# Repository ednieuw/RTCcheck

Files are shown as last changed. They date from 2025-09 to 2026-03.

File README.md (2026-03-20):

# RTC check
When using DS3231 time modules some are not functioning perfect.  

RTCcheckPCB

Check up to eight DS3231 RTC's using a TCA9548A I2C multiplexer and an Arduino UNO/Nano or Arduino Nano ESP32, ESP32 C3, S3 or similar.

<br>

Control the ESP32 RTC-tester with a WIFI/serial webpage, a BLESerial app or IDE serial monitor.

When a WS2812 or SK6812 LED-strip is attached colours indicate the drift of the RTC.
An optional LDR + 10kOhm resistor can be used to regulate the LED-intensity 

This ESP32-sketch is a little overkill for its use but easy for me to add it to an existing project.

Start a simple menu by sending 'i' from a (BLE) serial terminal.<br>
For functionality info see here: https://github.com/ednieuw/Arduino-ESP32-Nano-Wordclock <br>and here: https://github.com/ednieuw/ESP32Communications.<br>
The last link is this RTC-test sketch stripped from the RTC-test code.

A smaller sketch is included for the Arduino UNO, Nano or similar. 
This UNO compatible script has no NTP time but is perfect to use if three or more DS3231 are tested.<br>
The one that drifts can be identified easily.

<br>

And that some can drift after one month can be seen above.<br>
T5 was and not temperature controlled DS1307 AT24C32<br> 
T7 was a Keyestudio DS3231<br>
The others were AT24C32 DS3231 modules.<br>
T0 was drifting seriously.<br>
<br>
<br>
Breadboard design for three RTC's but can easily be expanded to eight RTC's. See pictures below.

<br>

RTCPCBv04

The PCBV04 design was made for the Adafruit TCA9548A I2C multiplexer that happens to be 2.54mm smaller than the cheap ones.<br>
In PCBV05 it is possible to use both widths.
In PCBV06 the SQW amd 32K pins of the DS3231 can be accessed on the PCB.

RTCPCBv05

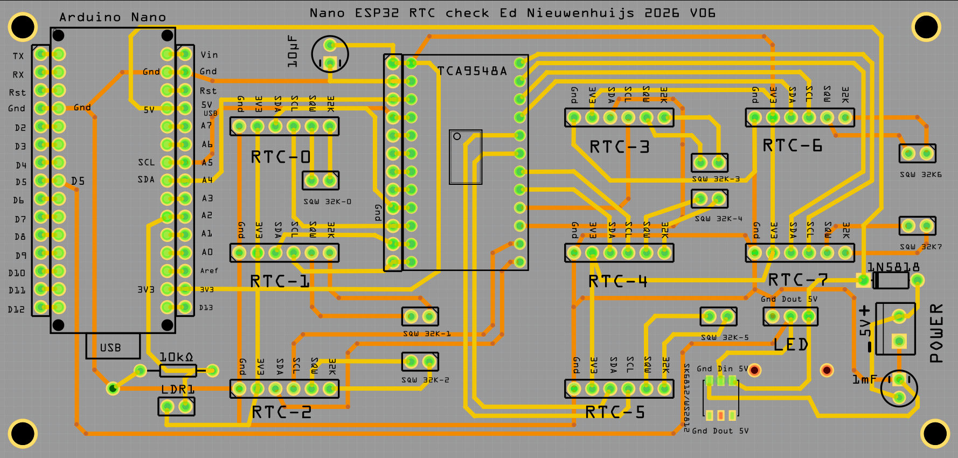
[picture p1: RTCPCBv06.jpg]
RTCPCBv06


Fritzing design with Gerber files can be found in this repository.<br>

Five PCB's [can be ordered from **PCBway**](https://www.pcbway.com) for ~25€ / $.<br> 
I am very happy with the PCB's they print for me. Just upload the Gerber-files and choose the colour of the PCB.<br> 
They are processed directly and arrive quick here in Europe. The quality is sublime and are easy to solder. 

The PCB is designed for an Arduino Nano ESP32. 

With this sketch and some wiring up to eight DS3231 modules can be tested using the NTP time server as reference.
The sketch connect with WIFI to internet and can be controlled with a BLE terminal app or the Arduino IDE serial terminal. 
```
RTC 0: 06/09/2025 17:39:30 T: 23.75 C
RTC 1: 06/09/2025 17:39:30 T: 24.25 C
RTC 2: 06/09/2025 17:39:30 T: 23.75 C
 Clock time: 06/09/2025 17:39:29 
   NTP time: 06/09/2025 17:39:30 
```

IMG_4759(1)
Running on Arduino Nano ESP32 with DS3231 connected to 3.3V pin.

IMG_4748(1)

Running on Arduino Nano Every with DS3231 connected to 5V pin. (But the DS3231's also run with the 3.3V pin)

```
___________________________________
I Menu, II long menu
F Print time differences from NTP
! See RTC times
& Update system time all RTC times
U Update system time in RTC U0-U7
R Reset settings
@ Restart
___________________________________
Slope: 1     Min: 1     Max: 255 
BLE name: RTCtest
IP-address: 192.168.178.94/update
WIFI=On NTP=On BLE=On FastBLE=Off
26/12/2025 16:03:10 
___________________________________

___________________________________
A SSID B Password C BLE beacon name
D Date (D15012021) T Time (T132145)
E Timezone  (E<-02>2 or E<+01>-1)
F Print time differences from NTP
G Scan WIFI networks
I Info menu, II long menu 
K LDR reads/sec toggle On/Off
N Display off between Nhhhh (N2208)
P Status LED toggle On/Off
R Reset settings, @ Reset MCU
U Update system time in RTC U0-U7
--Light intensity settings (1-250)--
S Slope, L Min, M Max  (S50 L5 M200)
W WIFI X NTP& Z WPS CCC BLE + Fast BLE
RTC: ! See, & Update all RTC's
Ed Nieuwenhuijs Nov 2025
___________________________________
Slope: 1     Min: 1     Max: 255 
SSID: FRITZ!BoxEd
BLE name: RTCtest
IP-address: 192.168.178.94/update
Timezone:CET-1CEST,M3.5.0,M10.5.0/3
WIFI=On NTP=On BLE=On FastBLE=Off
Rotary=Off Membrane=Off  DS3231=Off
WS2812 strip with 14 LEDs (switch %)
Software: ESP32_RTCcheckV011.ino
ESP32 Arduino core version: 3.3.5
26/12/2025 16:03:14 
___________________________________
```

<br>
Eight RTC's, a WS2812 LED-strip and LDR to control the LED intensity. 

### The Software
All the specific code for DS3231-test in this code is labelled with RTC8.

If searching for **RTC8** it is easy to find.  
```
//--------------------------------------------
// RTC8 
//-------------------------------------------- 
RTC_DS3231 rtc[MAX_RTC]; 
bool rtcActive[MAX_RTC] = {false};  
int activeRTCCount     = 0;

//--------------------------------------------
// RTC8 Initialyse all connected RTC's
//--------------------------------------------
void SetupRTCs(void) 
{
  Serial.println("DS3231 RTC Multiplexer Test");
  Serial.println("===========================");
  sprintf(sptext, "Software: %s", SoftwareName());  Tekstprintln(sptext);   
  
  Serial.print("TCA9548A search on addres 0x"); 

```

### Connect via Bluetooth
To make life easy it is preferred to use a phone or tablet and a Bluetooth communication app to enter the WIFI credentials into the clock.<br>

 	 	 
BLESerial nRF	BLE Serial Pro	Serial Bluetooth Terminal
- Download a Bluetooth UART serial terminal app on your phone, PC, or tablet.<br>

- For IOS iPhone or iPad (Buy this one to support me): [BLE Serial Pro](https://apps.apple.com/nl/app/ble-serial-pro/id1632245655?l=en).<br>
Or the free, less sophisticated app: [BLE serial nRF](https://apps.apple.com/nl/app/bleserial-nrf/id1632235163?l).<br>
Tip: Turn on Fast BLE with option + in the menu for a faster transmission.

- For Android use: [Serial Bluetooth terminal](https://play.google.com/store/apps/details?id=de.kai_morich.serial_bluetooth_terminal). <br>
Do not turn on Fast BLE in the menu. (Off = default)

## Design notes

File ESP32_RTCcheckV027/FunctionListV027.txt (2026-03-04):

void setup()                                                                                // ARDUINO Setup.
void loop()                                                                                 // ARDUINO Loop.
void loop2()                                                                                // ARDUINO Loop.
void CheckDevices(void)                                                                     // COMMON Check connected input devices.
void EverySecondCheck(void)                                                                 // COMMON Update routine.
void Every100mSecCheck(void)                                                                // COMMON Update routine.
void EveryMinuteUpdate(void)                                                                // COMMON Update routine done every minute.
void EveryHourUpdate(void)                                                                  // COMMON Update routine done every hour.
void EveryDayUpdate(void)                                                                   // COMMON Update routine done every day.
void UpdateStatusLEDs(int Toggle)                                                           // COMMON Update routine for the status LEDs.
void SetStatusLED(int Red, int Green, int Blue)                                             // COMMON Control the RGB LEDs on the Nano ESP32.
void SetNanoLED13(int intensity)                                                            // COMMON Control orange LED D13 on the Arduino.
void SetPCBLED09(int intensity)                                                             // COMMON Control the RGB LED on the PCB.
void SetPCBLED10(int intensity)                                                             // COMMON Control the RGB LED on the PCB.
void SerialCheck(void)                                                                      // COMMON check for serial input.
void Reset(void)                                                                            // COMMON Reset to default settings. BLE On, WIFI NTP Off.
void ResetCredentials(void)                                                                 // COMMON Reset to empty credential settings WIFI, NTP, BLE ON.
void Tekstprint(char const *tekst)                                                          // COMMON common print routines.
void Tekstprintln(char const *tekst)                                                        // COMMON common print routines.
void TekstSprint(char const *tekst)                                                         // COMMON common print routines.
void TekstSprintln(char const *tekst)                                                       // COMMON common print routines.
void Tekstprintf(const char* fmt, ...)                                                      // COMMON Formatted Tekst print.
void Tekstprintlnf(const char* fmt, ...)                                                    // COMMON Formatted Tekstprintln.
void WTekstappend(char const *tekst, char const *prefix, char const *suffix, bool newline)  // COMMON Print web menu page and BLE menu.
void WTekstprintln(char const *tekst)                                                       // COMMON Print web menu page and BLE menu.
void WTekstprintln(char const *tekst, char const *prefix, char const *suffix)               // COMMON Print web menu page and BLE menu.
void WTekstprint(char const *tekst)                                                         // COMMON Print web menu page and BLE menu.
void WTekstprint(char const *tekst, char const *prefix, char const *suffix)                 // COMMON Print web menu page and BLE menu.
int SConstrainInt(String s,byte first,byte last,int low,int up)                             // COMMON Constrain a string with integers.
int SConstrainInt(String s,byte first,          int low,int up)                             // COMMON Constrain a string with integers.
void InitStorage(void)                                                                      // COMMON Init and check contents of EEPROM.
void StoreStructInFlashMemory(void)                                                         // COMMON Store mem.struct in FlashStorage or SD.
void StoreIRRemoteInFlashMemory(void)                                                       // COMMON Save IR remote settings.
void GetStructFromFlashMemory(void)                                                         // COMMON Get data from FlashStorage.
void GetIRRemoteFromFlashMemory(void)                                                       // COMMON Load IR remote settings from FlashStorage.
void SWversion(void)                                                                        // COMMON Version info.
void SWversion(bool Small)                                                                  // COMMON Version info.
void PrintLine(byte Lengte)                                                                 // COMMON Print a _ line of n length.
void ReworkInputString(String InputString)                                                  // COMMON Input from Bluetooth, Serial or HTML page.
void PrintTimeInputMethod(byte Im)                                                          // COMMON Print time input method.
void PrintMem(void)                                                                         // COMMON Print permanent Mem memory.
void StoredStartHeaps()                                                                     // COMMON Print memory space.
void StoredStartHeaps(bool Store)                                                           // COMMON Print memory space.
void PrintHeaps(void)                                                                       // COMMON Print memory space.
int ReadLDR(void)                                                                           // COMMON LDR reading are between 0 and 255.
void Displaytime(void)                                                                      // CLOCK Say the time and load the LEDs.
void DimLeds(bool print)                                                                    // CLOCK Dim the leds measured by the LDR and print values.
void ColorLeds(char const *Tekst, int FirstLed, int LastLed, uint32_t RGBWColor)            // LED Set color for LEDs in strip and print tekst.
void ColorLed(int Lednr, uint32_t RGBWColor)                                                // LED Set color for LEDs in strip and print tekst.
void LedsOff(void)                                                                          // LED Clear display settings of the LEDs.
void Laatzien(int Delaymsec)                                                                // LED Turn On and the LEDs off after Delaymsec milliseconds.
void ShowLeds(void)                                                                         // LED Push data in LED strip to commit the changes.
void SetBrightnessLeds(byte Bright)                                                         // LED Set brighness of LEDs.
void Stripfill(uint32_t RGBWColor, int FirstLed, int NoofLEDs)                              // LED Set brighness of LEDs.
uint32_t StripGetPixelColor(int Lednr)                                                      // LED Set brighness of LEDs.
void LEDstartup(uint32_t LEDColour)                                                         // LED Synchronize the colour of the LEDstrip with the Status LED.
uint32_t HSVToRGB(double H, double S, double V)                                             // LED convert HSV to RGB  h is from 0-360, s,v values are 0-1.
uint32_t FuncCRGBW( uint32_t Red, uint32_t Green, uint32_t Blue, uint32_t White)            // LED function to make RGBW colour.
void ClearScreen(void)                                                                      // DISPLAY Clear the display.
void StartLeds(void)                                                                        // DISPLAY Initialyse the LEDstrip for WS2812 or SK6812 LEDs.
void WriteLightReducer(int amount)                                                          // CLOCK In- or decrease light intensity value i.e. Slope.
void InitTimeSystem(void)                                                                   // TIME Initialize time system (DS3231 + NTP + internal RTC).
void SetSystemTimeToCompileTime(void)                                                       // TIME Set system time to compile time using basic functions.
time_t GetTijd(bool printit)                                                                // TIME Get current time from best available source.
DateTime GetLocalDateTime()                                                                 // NTP Return local time as RTClib DateTime.
bool GetNTPtime(bool printit)                                                               // NTP print the NTP time for the timezone set.
bool IsDS3231I2Cconnected(void)                                                             // DS3231 check for I2C connection.
float GetDS3231Temp(void)                                                                   // DS3231 temperature.
void SetDS3231Time(void)                                                                    // DS3231 RTC ESP32 -> DS3231.
void GetDS3231Time(bool printit)                                                            // DS3231 reads time in module DS3231.
void PrintTimeHMS()                                                                         // RTC Fill sptext with time as HMS hh:mm:ss.
void PrintTimeHMS(byte format)                                                              // RTC Fill sptext with time as HMS hh:mm:ss.
void SetRTCTime(void)                                                                       // RTC Set time in ESP32 using global timeinfo struct.
void SetSystemTime(time_t t)                                                                // RTC Set RTC time using Unix timestamp.
void PrintAllClockTimes(void)                                                               // CLOCK Print all the times available.
void SendMessageBLE(std::string Message)                                                    // BLE SendMessage by BLE Slow in packets of 20 chars.
void StartBLEService(void)                                                                  // BLE Start BLE Service.
void CheckBLE(void)                                                                         // BLE Start BLE Service.
void WiFiEvent(WiFiEvent_t event)                                                           // WIFI WIFIEvents.
void ScanWIFI(void)                                                                         // WIFI Scan for WIFI stations and print a list of networks found.
void ConnectWIFI(void)                                                                      // WIFI Check for WIFI router SSID and password.
void CheckRestoreWIFIconnectivity(void)                                                     // WIFI Check if WIFI is still connected and if not restore it.
bool StartWIFI_NTP(void)                                                                    // WIFI Start WIFI connection and NTP service.
void NTPnotify(struct timeval* tv)                                                          // NTP functions.
void CheckandPrintNTPsynced(void)                                                           // NTP functions.
void setTimezone()                                                                          // NTP functions.
void initSNTP()                                                                             // NTP functions.
bool wait4SNTP()                                                                            // NTP Get a NTP time and wait max 2.5 sec.
void CheckWIFIcommand(void)                                                                 // WIFI Check for a Pending command received from the web page.
void WebPage(void)                                                                          // WIFI WEBPAGE.
void notFound(AsyncWebServerRequest *request)                                               // WIFI WEBPAGE.
void StartAPMode(void)                                                                      // WIFI WEBPAGE Login credentials Access Point page with 192.168.4.1.
void wpsInitConfig()                                                                        // WIFI WPS functions.
void wpsStart()                                                                             // WIFI WPS functions.
void wpsStop()                                                                              // WIFI WPS functions.
String wpspin2string(uint8_t a[])                                                           // WIFI WPS functions.
void OnewireKeypad3x4Check(void)                                                            // KEYPAD check for Onewire Keypad input.
void OnewireKeypad3x1Check(void)                                                            // KEYPAD check for Onewire Keypad input with 5V and 1.1, 4.7, 4.7, 4.7 kOhm resistors.
void Keypad3x1Check(void)                                                                   // KEYPAD 3x1 Init.
void RotaryEncoderCheck(void)                                                               // KY-040 ROTARY check if the rotary is moving.
void ProcessKeyPressTurn(int encoderPos)                                                    // CLOCK KY-040 Rotary or Membrane 3x1 processing input.
void Start_IRreceiver(void)                                                                 // IR-RECEIVER Start alarge or tiny IR-RECEIVER.
void Init_IRreceiver(String* ButtonTempNames, byte numButtons)                              // IR-RECEIVER Init.
uint16_t IrReceiverDecode(void)                                                             // IR-RECEIVER Decode received signal,.
void ProcessLearningMode(decode_type_t protocol, uint16_t command, uint16_t address)        // IR-RECEIVER Decode received signal,.
void ProcessRecognitionMode(decode_type_t protocol, uint16_t command, uint16_t address)     // IR-RECEIVER Decode received signal,.
void StartIRLearning(void)                                                                  // IR-RECEIVER Initializes learning mode.
void PrintAllMappings(void)                                                                 // IR-RECEIVER Shows learned buttons.
void ResetAllIRremoteSettings(void)                                                         // IR-RECEIVER Reset all settings.
int RecognizeButton(decode_type_t protocol, uint16_t command, uint16_t address)             // IR-RECEIVER Identifies button pressed.
void ReworkIRremoteValue(int ButtonNamesNr)                                                 // IR-RECEIVER ReworkRemoteValue.
void AdjustTime(int DeltaHours, int DeltaMinutes, int DeltaSeconds)                         // IR-RECEIVER Adjust current time by hours/minutes/seconds.
void ToggleIRpower(void)                                                                    // IR-RECEIVER Turn On or off Remote control.
void InitLogBuffer()                                                                        // LOGBUFFER Initialize circular logging buffer.
void AddLog(const char* msg)                                                                // LOGBUFFER Add a log line (raw C-string). Always ends with '\n'.
void HandleTekstPrint(AsyncWebServerRequest* request)                                       // LOGBUFFER Printlast 500 lines.
void HandleTekstDownload(AsyncWebServerRequest *request)                                    // LOGBUFFER Stream all the circular log buffer directly to the client.
void SetupRTCs(void)                                                                        // RTC8 Initialyse all connected RTC's.
void PrintRTCtimes(void)                                                                    // RTC8 Print RTC times.
void PrintDifRTCtimes(void)                                                                 // RTC8 Print RTC differences from NTP.
void UpdateRTCTimeLEDs(void)                                                                // RTC8 Update the time difference in the LEDs.
void CalcDifRTCtimes(void)                                                                  // RTC8 Calculate difference in sec from NTP.
void selectTCAChannel(uint8_t channel)                                                      // RTC8 Function to select TCA9548A channel.
void SetTimeForRTC(int rtcIndex, DateTime newTime)                                          // RTC8 set Time For RTC.
void SetNTPTimeForRTC(int rtcIndex)                                                         // RTC8 set current NTP Time For RTC Number X.
void PrintTimeForRTC(int rtcIndex)                                                          // RTC8 Print Time For RTC.
float GetTemperatureForRTC(int rtcIndex)                                                    // RTC8 get Temperature For RTC.
void SynchronizeAllRTCs()   // Zoek eerste actieve RTC als referentie                       // RTC8 Synchronize all RTC's with current time.
void SetCurrentTime()                                                                       // RTC8 Set time by hand in serial monitor.
void SetTempColor(int Lednr, float temp)                                                    // RTC8 Set Temperature Color.
float GetMedianRTCTemperature(void)                                                         // RTC8 Get media temperature of all active LEDs.

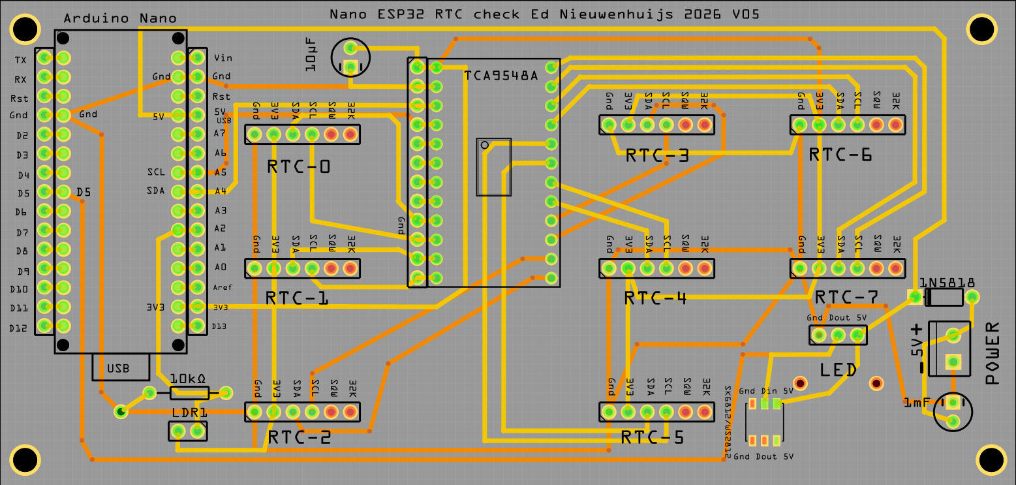
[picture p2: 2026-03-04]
PCBdesign/RTCPCBv05.jpg

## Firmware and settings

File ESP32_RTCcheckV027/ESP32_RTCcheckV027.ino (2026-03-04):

/* 
 Author      : Ed Nieuwenhuijs ednieuw.nl
 Changes V001: Derived from ESP32Arduino_WordClockV098.ino
 Changes V002:  
 Changes V003: LED crashes with some rmt error. Runs on ESP32-S3-WROOM-DevKitC-1
 Changes V004: WIFI not connecting. Added in StartAPmode()  xTaskCreatePinnedToCore(WebServerTask,"WebServerTask", 4096, NULL, 1, NULL, 1 ); 
 Changes V005: WIFI not connecting. Added WS2812 and SK6812 LED-strip functionality to GPIO-pin 8 
 Changes V006: Equal to ESP32Arduino_WordClockV105.ino
 Changes V007: crashes when using EDSoftLED
 Changes V008: Equal to ESP32Arduino_WordClockV112.ino
 Changes V009: Added Title in WebPage() 
 Changes V010: Time functions updated. You can compile now By Arduino pin (default)
 Changes V011: Equal to ESP32Arduino_WordClockV132.ino
 Changes V012: Equal to ESP32_WordClockV150. Added RTCcheck V011 
 Changes V013: NUMLED 1 -> 14 LEDS. snprintf in SWversion() Timestamp/min ||hour in menu
 Changes V014: Print time /min /ht /off K2 K1 K0
 Changes V015: Equal to ESP32Arduino_WordClockV153.ino
 Changes V016: Added DoNotLog flag. Removed action="/get" <form id="commandForm" action="/get">
               changed to char* :-> PrintRTCTime());PrintNTPtime());PrintUTCtime()); PrintDS3231Time());
 Changes V017: Double printing of menu in Logging solved. Option K2 debugged. Equal to ESP32_WordClockV159
 Changes V018: Cosmetic.
 Changes V019: Cosmetic. Equal to ESP32Arduino_WordClockV160.ino
 Changes V020: Stable 
 Changes V021: Added option U in menu 
 Changes V022: Ringbuffer as in woordclockV183
 Changes V023: Cleaning up and cosmetics.  
 Changes V024: Ringbuffer long log file as download
 Changes V025: Temp -10C _ 60C -> 15C _ 25C
 Changes V026: Added CheckWIFIcommand() to avoid WIFI crashes when a command take several seconds to end, like LEDtest()
 Changes V026: changed delimiters in time log. Temp  15C _ 25C -> 10C - 30C and color calculation  LED10.
*********************
How to compile: 
Install ESP32 boards
Board: ESP32 core version >3.2.0 
Partition Scheme: With FAT
Pin Numbering: By Arduino pin (default)     -- > with EdsoftLED both can be used
               By GPIO number (legacy).     -- > When using NEOpixel
               when using By Arduino pin Error: Adafruit_NeoPixel/esp.c:78:(.text.espShow+0x55): undefined reference to `digitalPinToGPIONumber' 
USB mode: Normal (Tiny USB)
**********************

ESP32-S3-WROOM-DevKitC-1
Option	    Value
Board:      ESP32-S3 DEV Module on ESP32 core 3.3.3 
USB         CDC on Boot	Enabled
USB Mode	  Hardware CDC and JTAG (or just Hardware CDC)
Upload Mode	UART0 / Hardware Serial
Flash Mode	QIO 80MHz (default, or leave unchanged)
Port	      Select the UART COM port (the one with a USB-to-Serial chip)

*/
// =============================================================================================================================

//------------------------------------------------------------------------------              //
// ESP32 Includes defines and initialisations
//--------------------------------------------
                      #if ESP_ARDUINO_VERSION >= ESP_ARDUINO_VERSION_VAL (5, 2, 0)            // Use EdSoftLED with ESP32 compiler.
#define USEEDSOFTLED  // Sometimes a flicker with Core 3.3.3 NEOPIXEL worka now also OK but need to set By GPIO number
                      #endif
                      #ifdef USEEDSOFTLED
#include <EdSoftLED.h>         // https://github.com/ednieuw/EdSoftLED for LED strip WS2812 or SK6812 
                      #else
#include <Adafruit_NeoPixel.h> // https://github.com/adafruit/Adafruit_NeoPixel  *** USE GPIO NUMBERING and compile By GPIO number (legacy) 
                      #endif
#include <Preferences.h>
#include <NimBLEDevice.h>      // For BLE communication. !!!Use NimBLE version 2.x.x  https://github.com/h2zero/NimBLE-Arduino
#include <WiFi.h>              // Used for web page 
#include <esp_sntp.h>          // for NTP
#include <esp_wps.h>           // For WPS
#include <ESPAsyncWebServer.h> // Used for webpage  https://github.com/ESP32Async 
#include <Update.h>            // For Over-the-Air (OTA)
#include <ESPmDNS.h>           // To show BLEname in router
#include <DNSServer.h>         // For the web page to enter SSID and password of the WIFI router 
#include <Wire.h>              // Ter zijner tijd Wire functies gaan gebruiken. Staan al klaar in de code 
#include <RTClib.h>            // Used for connected DS3231 RTC // Reference https://adafruit.github.io/RTClib/html/class_r_t_c___d_s3231.html
#include <Encoder.h>           // For rotary encoder
#include <Keypad.h>            // For 3x1 membrane keypad instead of rotary encoder by Mark Stanley & Alexander Brevig 
#include <IRremote.hpp>        // IR remote control

//------------------------------------------------------------------------------              //
// SPIFFS storage
//--------------------------------------------
Preferences FLASHSTOR;

                           #if defined(ARDUINO_NANO_ESP32)
//------------------------------------------------------------------------------              //
// PIN Assigments for Arduino Nano ESP32 (S3)
//------------------------------------------------------------------------------
 
enum DigitalPinAssignments {      // Digital hardware constants ATMEGA 328 ----
 SERRX        = D0,               // Connects to Bluetooth TX
 SERTX        = D1,               // Connects to Bluetooth RX
 encoderPinB  = D2,               //5,  // D2 left (labeled CLK on decoder)no interrupt pin (Use GPIO pin numbering for rotary encoder lib)  
 encoderPinA  = D3,               //6,  // D3 right (labeled DT on decoder)on interrupt pin
 clearButton  = D4,               //7,  // D4 switch (labeled SW on decoder)
 IRReceiverPin= D4,               // D4 Infrared receiver pin instead of rotary encoder
 LED_PIN      = D5,               //8,  // D5 / GPIO 8 Pin to control colour SK6812/WS2812 LEDs (replace D5 with 8 for NeoPixel lib)
 EmptyD6      = D6,               // D6 Empty
 EmptyD7      = D7,               // D7 Empty
 EmptyD8      = D8,               // D8 Empty 
 PCB_LED_D09  = D9,               // D9
 PCB_LED_D10  = D10,              // D10
 secondsPin   = D13               //48, // D13  GPIO48 (#ifdef LED_BUILTIN  #undef LED_BUILTIN #define LED_BUILTIN 48 #endif)
 };
 
enum AnaloguePinAssignments {     // Analogue hardware constants ----
 EmptyA0      = A0,               // Empty
 EmptyA1      = A1,               // Empty
 PhotoCellPin = A2,               // LDR pin
 OneWirePin   = A3,               // OneWirePin
 SDA_pin      = A4,               // SDA pin
 SCL_pin      = A5,               // SCL pin
 EmptyA6      = A6,               // Empty
 EmptyA7      = A7};              // Empty
 
                                  #else

//------------------------------------------------------------------------------              //
// PIN Assigments for ESP32 S3 DevKitC 1
//------------------------------------------------------------------------------  
enum DigitalPinAssignments {      // Digital hardware constants ATMEGA 328 ----
 SERRX        = 44,               // D1 Connects to Bluetooth TX
 SERTX        = 43,               // D0 Connects to Bluetooth RX
 encoderPinB  = 4,                // D2 left (labeled CLK on decoder)no interrupt pin (Use GPIO pin numbering for rotary encoder lib)  
 encoderPinA  = 5,                // D3 right (labeled DT on decoder)on interrupt pin
 clearButton  = 6,                // D4 switch (labeled SW on decoder)
 IRReceiverPin= 6,                // D4 Infrared receiver pin instead of rotary encoder
 LED_PIN      = 48,               // D5 / GPIO 8 Pin to control colour SK6812/WS2812 LEDs (replace D5 with 8 for NeoPixel lib)
 PCB_LED_D09  = 10,               // D9
 PCB_LED_D10  = 11,               // D10
 secondsPin   = 13,               // D13  GPIO48 (#ifdef LED_BUILTIN  #undef LED_BUILTIN #define LED_BUILTIN 48 #endif)
 };
 
enum AnaloguePinAssignments {     // Analogue hardware constants ----
 EmptyA0      = 10,               // Empty
 EmptyA1      = 11,               // Empty
 PhotoCellPin = 12,               // LDR pin
 OneWirePin   = 13,               // OneWirePin
 SDA_pin      = 8,                // SDA pin
 SCL_pin      = 9,                // SCL pin
 EmptyA6      = 16,               // Empty
 EmptyA7     =  17};              // Empty
                          #endif //defined(ARDUINO_NANO_ESP32)
//------------------------------------------------------------------------------              //
// LED
//------------------------------------------------------------------------------

const uint32_t  NUM_LEDS = 10;  // Used strip is 14 LEDs long. Will now clear all the LEDs at startup
#define CLEARLEDSTARTUP 9999
                     #ifdef USEEDSOFTLED
EdSoftLED LEDstrip ;//    = EdSoftLED();                                                      // Use EdSoftLED with ESP32 compiler V3.x.x. Neopixel crashes
EdSoftLED LED6812strip = EdSoftLED(NUM_LEDS, LED_PIN, SK6812WRGB);
EdSoftLED LED2812strip = EdSoftLED(NUM_LEDS, LED_PIN, WS2812RGB);
bool UsedEDSOFTLED = true;
                      #else
// LED_PIN = 8;  // bug in Neopixel library. Does not translate D5 to GPIO 8
Adafruit_NeoPixel LEDstrip;
Adafruit_NeoPixel LED6812strip = Adafruit_NeoPixel(NUM_LEDS, LED_PIN, NEO_GRBW + NEO_KHZ800); // NEO_RGBW
Adafruit_NeoPixel LED2812strip = Adafruit_NeoPixel(NUM_LEDS, LED_PIN, NEO_GRB  + NEO_KHZ800); // NEO_RGB NEO_GRB
bool UsedEDSOFTLED = false;
                      #endif
// #define MCULEDPIN 9
// Adafruit_NeoPixel MCUled = Adafruit_NeoPixel(1, MCULEDPIN, NEO_GRB + NEO_KHZ800);  //NEO_RGB NEO_GRB

//------------------------------------------------------------------------------              //
const uint32_t black    = 0x000000, darkorange    = 0xFF8C00, red        = 0xFF0000, chartreuse   = 0x7FFF00;
const uint32_t brown    = 0x503000, cyberyellow   = 0xFFD300, orange     = 0xFF8000; 
const uint32_t yellow   = 0xFFFF00, cadmiumyellow = 0xFFF600, dyellow    = 0xFFAA00, chromeyellow = 0xFFA700;
const uint32_t green    = 0x00FF00, brightgreen   = 0x66FF00, apple      = 0x80FF00, grass        = 0x00FF80;  
const uint32_t amaranth = 0xE52B50, edamaranth    = 0xFF0050, amber      = 0xFF7E00;
const uint32_t marine   = 0x0080FF, darkviolet    = 0x800080, pink       = 0xFF0080, purple       = 0xFF00FF; 
const uint32_t blue     = 0x0000FF, cerulean      = 0x007BA7, sky        = 0x00FFFF, capri        = 0x00BFFF;
const uint32_t edviolet = 0X7500BC, frenchviolet  = 0X8806CE, coquelicot = 0xFF3800;
const uint32_t greenblue= 0x00F2A0, hotmagenta    = 0xFF00BF, dodgerblue = 0x0073FF, screamingreen= 0x70FF70;
      uint32_t white    = 0xFFFFFF, lgray         = 0x666666, wgray      = 0xAAAAAA;
      uint32_t gray     = 0x333333, dgray         = 0x222222;  

//--------------------------------------------
// DS3231 CLOCK MODULE
//--------------------------------------------
#define DS3231_I2C_ADDRESS          0x68
#define DS3231_TEMPERATURE_MSB      0x11
#define DS3231_TEMPERATURE_LSB      0x12
RTC_DS3231 RTCklok; 
bool DS3231Installed = false;                                                                 // True if the DS3231 is detected

#define TCA_ADDR 0x70                 // RTC8                                                // TCA9548A I2C multiplexer adres (standaard 0x70)
#define MAX_RTC 8                     // RTC8                                                // Maximaal Noof RTC modules
uint32_t RTCdiffSec[MAX_RTC];         // RTC8                                                // Seconds deviating from NTP time

//------------------------------------------------------------------------------              //
// KY-040 ROTARY
//------------------------------------------------------------------------------                       
Encoder myEnc(encoderPinA, encoderPinB);                                                      // Use digital pin  for encoder    
long     Looptime             = 0;
byte     RotaryPress          = 0;                                                            // Keeps track display choice and how often the rotary is pressed.
bool     ChangeLightIntensity = false;                                                        // Increase or decrease slope light intensity        
uint32_t RotaryPressTimer     = 0;
byte     NoofRotaryPressed    = 0;

//--------------------------------------------                                                //
// One-wire keypad
//--------------------------------------------
bool     ChangeTime           = false;                                                        // Flag to change time within 60 seconds       
uint64_t KeyLooptime          = 0;
String   KeypadString         ="";
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
void loop() 
{
 Loopcounter++;                                                                               // a counter to check the speed of the loop
 CheckDevices();                                                                              // Check input from devices
 EverySecondCheck();                                                                          // Enter the command structure
}
void loop2()
{

}
//--------------------------------------------                                                //
// COMMON Check connected input devices
//--------------------------------------------
void CheckDevices(void)
{
 CheckBLE();                                                                                  // Something with BLE to do?
 SerialCheck();                                                                               // Check serial port every second 
 CheckWIFIcommand();                                                                          // Check if there is a command given from the web page
 if (Mem.UseRotary==1) RotaryEncoderCheck(); 
 if (Mem.UseRotary==2) Keypad3x1Check();
}
//--------------------------------------------                                                //
// COMMON Update routine 
// Performs tasks every second
//--------------------------------------------
void EverySecondCheck(void)
{
 static bool Toggle = 0;
 uint32_t msLeap = millis() - msTick;                                                         //
 if (msLeap % 100) Every100mSecCheck();
 if (msLeap > 999)                                                                             // Every second enter the loop
 {
  msTick = millis();
  GetTijd(false);                                                                             // Get the time for the seconds 
 
  Toggle = !Toggle;                                                                          // Used to turn On or Off Leds
  UpdateStatusLEDs(Toggle);
  DimLeds(TestLDR);                                                                           // Every second an intensity check and update from LDR reading 
  // SetTempColor(8, timeinfo.tm_sec/2);    
  if (shouldReboot) { delay(1000);   ESP.restart(); }                                         // After finish OTA update restart
  if (timeinfo.tm_min != lastminute) EveryMinuteUpdate();                                     // Enter the every minute routine after one minute; 
  Loopcounter=0;
 }  
}

//--------------------------------------------                                                //
// COMMON Update routine 
// Performs tasks every second
//--------------------------------------------
void Every100mSecCheck(void)
{
 if (Mem.UseRotary==3 || Mem.UseRotary==4) IrReceiverDecode();
}
//--------------------------------------------                                                //
// COMMON Update routine done every minute
//-------------------------------------------- 
void EveryMinuteUpdate(void)
{   
 lastminute = timeinfo.tm_min;  
 if (IR_PowerOnstate && ((millis() - IR_StartTime) > 290000) ) ToggleIRpower();               // Turn off Power after 300 seconds 
 GetTijd(false);
 bool ff = NoTextInLeds; 
 if (Mem.TimeMinute == 0 || Mem.TimeMinute == 2)                                              // Do not print time but do update the display                                                              // do not Print the time string every minute
    { NoTextInLeds = true; DimLeds(false); Displaytime(); }
 if (Mem.TimeMinute == 1)                                                                     // Print the time string every minute
    { NoTextInLeds = false; DimLeds(true);  Displaytime(); Tekstprintln(""); }
 NoTextInLeds = ff;   
 DimLeds(false);                                                                              // 
 if(timeinfo.tm_hour != lasthour) EveryHourUpdate();                                                                            //  if(timeinfo.tm_hour != lasthour) EveryHourUpdate(); 
}
//--------------------------------------------                                                //
// COMMON Update routine done every hour
//--------------------------------------------
void EveryHourUpdate(void)
{
 lasthour = timeinfo.tm_hour;
 if (!Mem.StatusLEDOn) SetStatusLED(0,0,0);                                                   // During startup this EveryHourUpdate is run once and will turn the status LEDs of  
 bool ff = NoTextInLeds; 
 if (Mem.TimeMinute == 2)                                                                     // Print the time string every hour
    { NoTextInLeds = false; DimLeds(true); Displaytime(); Tekstprintln(""); }
 NoTextInLeds = true; 
 Displaytime(); 
 NoTextInLeds = ff;                                                                          // Print time per hour
 if((timeinfo.tm_hour == Mem.TurnOffLEDsAtHH) && (Mem.TurnOffLEDsAtHH != Mem.TurnOnLEDsAtHH))
   { LEDsAreOff = true;  ClearScreen(); }                                                     // Is it time to turn off the LEDs?
 if(timeinfo.tm_hour == Mem.TurnOnLEDsAtHH)
   { LEDsAreOff = false;   lastminute = 99; Displaytime(); Tekstprintln(""); }                // Force a minute update to turn on LEDs
 CheckRestoreWIFIconnectivity();                                                              // Check if WIFI is still connected and if not restore it
 Mem.NVRAMmem[lasthour] =(byte)((SumLDRreadshour / NoofLDRreadshour?NoofLDRreadshour:1));     // Update the average LDR readings per hour
 SumLDRreadshour  = 0;
 NoofLDRreadshour = 0;                                                                        // and DimLEDs are used to print the time every hour 
 if (timeinfo.tm_mday != lastday) EveryDayUpdate();  
}

//--------------------------------------------                                                //
// COMMON Update routine done every day
//--------------------------------------------
void EveryDayUpdate(void)
{
 lastday           = timeinfo.tm_mday; 
 Previous_LDR_read = ReadLDR();                                                               // to have a start value and reset the Min Max measurements 
 MinPhotocell      = Previous_LDR_read;                                                       // Stores minimum reading of photocell;
 MaxPhotocell      = Previous_LDR_read;                                                       // Stores maximum reading of photocell;
// if(DS3231Installed && !Mem.UseDS3231) SetDS3231Time();                                       // If on NTP time and DS3231 installed set the correct the time in the DS3231 
 Tekstprintln(PrintRTCTime());                                                                // Print time as dd-mmm-yy hh:mm:ss
 StoreStructInFlashMemory();                                                                  // Update Mem struct once a day to store Mem.NVRAM measurementd
}

//--------------------------------------------                                                //
// COMMON Update routine for the status LEDs
//-------------------------------------------- 
void UpdateStatusLEDs(int Toggle)
{
 if(Mem.StatusLEDOn)   
   {
    SetStatusLED((Toggle && WiFi.localIP()[0]==0) * 20, 
                 (Toggle && WiFi.localIP()[0]!=0) * 20 , 
                 (Toggle &&      deviceConnected) * 20);
    SetPCBLED09( Toggle * 10);                                                                // Left LED
    SetPCBLED10((!Toggle) * 10);                                                              // Right LED
    SetNanoLED13((!Toggle) * (!Mem.UseDS3231 * 50));                                         // LED on ESP32 board. IF DS3231 in use then it is off
   }
   else
   {
    SetStatusLED(0, 0, 0); 
    SetPCBLED09(0);                                                                           //
    SetPCBLED10(0);                                                                           //
    SetNanoLED13(0);      
   }
}
//--------------------------------------------                                                //
// COMMON Control the RGB LEDs on the Nano ESP32
// Analog range 0 - 512. 0 is LED Off, 512 is max intensity
// 512 is LED off. Therefore the value is subtracted from 512
// in core 3 the value to write is 13-bit 8191 to turn off the led completely
//  rgbLedWrite(512-Red,512-Green,512-Blue);
//--------------------------------------------
void SetStatusLED(int Red, int Green, int Blue)
{
 analogWrite(LED_RED,   Red   == 0 ? 8191 : (512 - Red));
 analogWrite(LED_GREEN, Green == 0 ? 8191 : (512 - Green));
 analogWrite(LED_BLUE,  Blue  == 0 ? 8191 : (512 - Blue));
}
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

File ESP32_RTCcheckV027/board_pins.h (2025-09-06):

// board_pins.h
// Unified pin definitions for ESP32 families and Arduino Nano ESP32
// Shows used pins, safe unused pins, and unsafe pins (documented)
// Makes it easy to keep track of pin usage across boards

#pragma once

// -----------------------------------------------------------------------------
// Manual board selection (uncomment one if needed)
// #define BOARD_ESP32_S3
// #define BOARD_ESP32_C3
// #define BOARD_ESP32_H2
// #define BOARD_ARDUINO_NANO_ESP32

// -----------------------------------------------------------------------------
// Auto-detect
#if !defined(BOARD_ESP32_S3) && !defined(BOARD_ESP32_C3) && \
    !defined(BOARD_ESP32_H2) && !defined(BOARD_ARDUINO_NANO_ESP32)

  #if defined(ARDUINO_ESP32S3_DEV) || defined(CONFIG_IDF_TARGET_ESP32S3)
    #define BOARD_ESP32_S3
  #elif defined(ARDUINO_ESP32C3_DEV) || defined(CONFIG_IDF_TARGET_ESP32C3)
    #define BOARD_ESP32_C3
  #elif defined(ARDUINO_ESP32H2_DEV) || defined(CONFIG_IDF_TARGET_ESP32H2)
    #define BOARD_ESP32_H2
  #elif defined(ARDUINO_NANO_ESP32)
    #define BOARD_ARDUINO_NANO_ESP32
  #else
    #warning "Unknown board: please define BOARD_ESP32_S3 / C3 / H2 / NANO manually"
  #endif
#endif

// -----------------------------------------------------------------------------
// ESP32-S3
// Safe GPIOs: 1–14, 16–21, 33–48
#ifdef BOARD_ESP32_S3

  // ⚠️ Unsafe pins (don’t use!)
  // 0 = strapping (boot), 15 = USB D-, 16/17 = USB D+ (if native USB),
  // 19/20 = XTAL, 46 = strapping
  // Flash/PSRAM pins: 26–32 (not exposed)

  // ➖ Empty safe pins
   #define PIN_BTN       0
  #define EMPTY_01   1
  #define EMPTY_02   2
  #define EMPTY_03   3
  #define EMPTY_04   4
  #define EMPTY_05   5
  #define EMPTY_06   6
  #define EMPTY_07   7
  #define PIN_LED       8
  #define EMPTY_09   9
  #define EMPTY_10   10
  #define EMPTY_11   11
  #define EMPTY_12   12
  #define EMPTY_13   13
  #define EMPTY_14   14
  #define PIN_I2C_SCL   17
  #define PIN_I2C_SDA   18
  #define EMPTY_21   21
  #define EMPTY_33   33
  #define EMPTY_34   34
  #define EMPTY_35   35
  #define EMPTY_36   36
  #define EMPTY_37   37
  #define EMPTY_38   38
  #define EMPTY_39   39
  #define EMPTY_40   40
  #define EMPTY_41   41
  #define EMPTY_42   42
  #define PIN_UART_TX   43
  #define PIN_UART_RX   44
  #define EMPTY_45   45
  #define EMPTY_47   47
  #define EMPTY_48   48
#endif

// -----------------------------------------------------------------------------
// ESP32-C3
// Safe GPIOs: 0–10, 18–21
#ifdef BOARD_ESP32_C3

  // ⚠️ Unsafe pins (don’t use!)
  // 11–17 = SPI flash/PSRAM (internal use)

  // ➖ Empty safe pins
  #define EMPTY_00   0
  #define EMPTY_01   1
  #define EMPTY_02   2
  #define EMPTY_03   3
  #define PIN_I2C_SDA   4
  #define PIN_I2C_SCL   5
  #define EMPTY_06   6
  #define EMPTY_07   7
  #define PIN_LED       8
  #define PIN_BTN       9
  #define EMPTY_10   10
  #define EMPTY_18   18
  #define EMPTY_19   19
  #define PIN_UART_TX   21
  #define PIN_UART_RX   20  
#endif

// -----------------------------------------------------------------------------
// ESP32-H2
// Safe GPIOs: 0–21, 26–27
#ifdef BOARD_ESP32_H2

  // ⚠️ Unsafe pins (don’t use!)
  // 22–25 = radio/oscillator
  // 28+ = N/A on most packages

  // ➖ Empty safe pins
  #define EMPTY_00   0
  #define EMPTY_01   1
  #define EMPTY_02   2
  #define EMPTY_03   3
  #define PIN_I2C_SDA   4
  #define PIN_I2C_SCL   5
  #define EMPTY_06   6
  #define EMPTY_07   7
  #define PIN_LED       8
  #define PIN_BTN       9
  #define EMPTY_10   10
  #define EMPTY_11   11
  #define EMPTY_12   12
  #define EMPTY_13   13
  #define EMPTY_14   14
  #define EMPTY_15   15
  #define EMPTY_16   16
  #define EMPTY_17   17
  #define EMPTY_18   18
  #define EMPTY_19   19
  #define PIN_UART_TX   20
  #define PIN_UART_RX   21
  #define EMPTY_26   26
  #define EMPTY_27   27
#endif

// -----------------------------------------------------------------------------
// Arduino Nano ESP32
// Uses Arduino Dx / Ax macros
#ifdef BOARD_ARDUINO_NANO_ESP32

  // ⚠️ Unsafe pins
  // Depends on Nano ESP32 design; usually USB, flash and RF pins are abstracted away
 
  // ➖ Digital pins

  #define PIN_UART_RX   D0
  #define PIN_UART_TX   D1
  #define EMPTY_D2   D2
  #define EMPTY_D3   D3
  #define EMPTY_D4   D4
  #define EMPTY_D5   D5
  #define EMPTY_D6   D6
  #define EMPTY_D7   D7
  #define EMPTY_D8   D8
  #define PIN_BTN      D9
  #define EMPTY_D10  D10
  #define EMPTY_D11  D11
  #define EMPTY_D12  D12
  #define EMPTY_D13  D13
  #define PIN_LED       LED_BUILTIN

  // ➖ Analog pins
  #define EMPTY_A0   A0
  #define EMPTY_A1   A1
  #define EMPTY_A2   A2
  #define EMPTY_A3   A3
  #define PIN_I2C_SDA   A4
  #define PIN_I2C_SCL   A5
  #define EMPTY_A6   A6
  #define EMPTY_A7   A7
#endif

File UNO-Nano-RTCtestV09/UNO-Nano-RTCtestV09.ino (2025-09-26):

#include <Wire.h>
#include <RTClib.h>

#define TCA_ADDR 0x70                                                // TCA9548A I2C multiplexer adres (standaard 0x70)
#define MAX_RTC 8                                                    // Maximaal Noof RTC modules
#define FILENAAM (strrchr(__FILE__, '\\') ? strrchr(__FILE__, '\\') + 1 : __FILE__) 

RTC_DS3231 rtc[MAX_RTC];                                             // RTC objecten aanmaken
static uint32_t msTick;                                              // Number of millisecond ticks since we last incremented the second counter
bool rtcActive[MAX_RTC] = {false};                                   // Array om bij te houden welke RTC's werkend zijn
int activeRTCCount     = 0;
uint32_t  Loopcounter  = 0;                                          // Loop speed counter
char sptext[255];                                                    // text print buffer

//--------------------------------------------                       //
// SETUP
//--------------------------------------------
void setup() 
{
  Serial.begin(115200);
  Wire.begin();

  Serial.println("DS3231 RTC Multiplexer Test");
  Serial.println("===========================");
   sprintf(sptext,"Software: %s",FILENAAM); Tekstprintln(sptext);   
  
  Serial.print("TCA9548A search on addres 0x");                      // Test or TCA9548A is available
  Serial.print(TCA_ADDR, HEX);
  Serial.print("... ");
  
  Wire.beginTransmission(TCA_ADDR);
  if (Wire.endTransmission() == 0) {
    Serial.println("FOUND!");
  } else {
    Serial.println("NOT FOUND!");
    Serial.println("check wiring and power");
    while(1);                                                       // 
  }  
  Serial.println("\nScanning DS3231 modules...");                   // Scan which channels a DS3231 has
  for (int i = 0; i < MAX_RTC; i++) 
   {
    selectTCAChannel(i);
    delay(50); 
    Wire.beginTransmission(0x68);                                   // DS3231 address
    uint8_t error = Wire.endTransmission();
    
    if (error == 0) 
     {
      Serial.print("DS3231 found on channel ");
      Serial.println(i);
     } 
     else
     {
      Serial.print("No DS3231 on channel ");
      Serial.print(i);
      Serial.print(" (Error: ");
      Serial.print(error);
      Serial.println(")");
     }
  }
  Serial.println("\nInitialising RTC modules...");                   // Initialiseonly found RTC modules
  for (int i = 0; i < MAX_RTC; i++) 
  {
    selectTCAChannel(i);                                             // Select multiplexer channel
    delay(50);
    
    Serial.print("Initialising RTC ");
    Serial.print(i);
    Serial.print("... ");
    
    // Test eerst of er een device is
    Wire.beginTransmission(0x68);
    if (Wire.endTransmission() != 0) 
    {
      Serial.println("NO DEVICE");
      continue;
    }
    
    if (!rtc[i].begin()) {
      Serial.println("FAILED!");
      Serial.println("Check connection on channel " + String(i));
      rtcActive[i] = false;
    } else {
      Serial.println("OK!");
      rtcActive[i] = true;
      activeRTCCount++;
      
      
      DateTime now = rtc[i].now();                                   // Show current
      sprintf(sptext,"Before update: %02d/%02d/%04d %02d:%02d:%02d ", now.day(),now.month(),now.year(),
                                                  now.hour(),now.minute(),now.second());
      Tekstprintln(sptext);
      
      // // Set time to compilation time
      // DateTime compileTime = DateTime(F(__DATE__), F(__TIME__));
      // Serial.print("  Time set to: ");
      // Serial.println(compileTime.timestamp(DateTime::TIMESTAMP_FULL));
      // rtc[i].adjust(compileTime);
      // delay(100);

      DateTime newTime = rtc[i].now();                               // Check time set
      sprintf(sptext," After update: %02d/%02d/%04d %02d:%02d:%02d ", newTime.day(),newTime.month(),newTime.year(),
                                                  newTime.hour(),newTime.minute(),newTime.second());
      Tekstprintln(sptext);  
    }
    delay(200); 
  }
  
  Serial.print("Setup finished! ");
  Serial.print(activeRTCCount);
  Serial.println(" RTC modules active.");
  Serial.println();
}
//--------------------------------------------                       //
// LOOP
//--------------------------------------------
void loop() 
{
  CheckSerialInput();
  Every5SecondCheck(); 
}

//--------------------------------------------                       //
// COMMON Update routine 
// Performs tasks every 5 seconds
//--------------------------------------------
void Every5SecondCheck(void)
{
 uint32_t msLeap = millis() - msTick;                                // 
 Loopcounter++;
 if (msLeap >4999)                                                   // Every 5 second enter the loop
 {
   msTick = millis();
   Loopcounter /= 5;
   PrintRTCtimes();
   Loopcounter = 0;
 }  
}

//--------------------------------------------                       //
// Check voor seriële input voor commando's
//-------------------------------------------- 
void CheckSerialInput(void)
{
  if (Serial.available() > 0) 
  {
    String command = Serial.readStringUntil('\n');
    command.trim();
    
    if (command == "sync") 
    {
      synchronizeAllRTCs();
      return;
    }
    if (command == "set") {
      setCurrentTime();
      return;
    }
    if (command == "help") {
      Serial.println("available commands:");
      Serial.println("  sync - Synchroniseer all RTC's with RTC 0");
      Serial.println("  set  - Enter specific time");
      Serial.println("  help - this help");
      return;
    }
  }
}
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

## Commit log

2025-09-06 RTC-V002
    Changes V008: Equal to ESP32Arduino_WordClockV112.ino
    Changes V001: It runs
    Changes V002: Added functions in menu
    Changes V003:
2025-09-06 V003
    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
2025-09-06 V003
    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
2025-09-26 V006
    Changes V003: RGB LEDs added, CalcDifRTCtimes
    Changes V004:
    Changes V005: Corrected extra output option F from menu
    Changes V006: changed second deviation LED colours
    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
    [ESP32_RTCcheckV003.ino, ESP32_RTCcheckV005.ino, ESP32_RTCcheckV006.ino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]
2025-10-12 V009
    Changes V007: Added Title in WebPage()
    Changes V008: Tekstprint ipv Serial.print
    Changes V009: Time functions updated. You can compile now By Arduino pin (default)
2025-12-26 Improve README clarity and functionality description
    Updated README to clarify functionality and usage of the ESP32 sketch.
2025-12-26 Update README with DS3231 drift information
    Added details about temperature-controlled devices and drift observations.
2025-12-26 Fix title and update Arduino model references
    Updated project title and clarified Arduino compatibility.
2025-12-27 Update README with design and ordering information
    Added details about breadboard design, Fritzing design, and PCB ordering.
2025-12-27 Revise PCB ordering details in README
    Updated PCB ordering information and emphasized PCBway.
2025-12-27 Update LED strip description in README
2025-12-28 Enhance README with ESP32 control and LED details
    Added information about controlling the ESP32 and LED indicators.
2025-12-29 V013
    Changes V011: Equal to ESP32Arduino_WordClockV132.ino
    Changes V012: Equal to ESP32_WordClockV150. Added RTCcheck V011
    Changes V013: NUMLED 1 -> 14 LEDS. snprintf in SWversion() Timestamp/min ||hour in menu
2025-12-30 V015
    Changes V014: Print time /min /ht /off K2 K1 K0
    Changes V015: Equal to ESP32Arduino_WordClockV153.ino
    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
    [partitions.csv]
2026-01-02 V019
    Changes V016: Added DoNotLog flag. Removed action="/get" <form id="commandForm" action="/get">
    changed to char* :-> PrintRTCTime());PrintNTPtime());PrintUTCtime()); PrintDS3231Time());
    Changes V017: Double printing of menu in Logging solved. Option K2 debugged. Equal to ESP32_WordClockV159
    Changes V018: Cosmetic.
    Changes V019: Cosmetic. Equal to ESP32Arduino_WordClockV160.ino
    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
    [partitions.csv]
2026-01-03 V020
    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
    [ESP32_RTCcheckV019.ino, ESP32_RTCcheckV020.ino, board_pins.h]
2026-02-17 Clarify ESP32 control and fix typos in README
    Updated README to clarify ESP32 RTC-tester control and corrected typos.
2026-02-21 V023
    Changes V020: Stable
    Changes V021: Added option U in menu
    Changes V022: Ringbuffer as in woordclockV183
    Changes V023: Cleaning up and cosmetics.
    [partitions.csv]
2026-02-22 V024
    Changes V024: Ringbuffer long log file as download
    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
    [partitions.csv]
2026-02-25 V025
    Changes V025: Temp -10C _ 60C -> 15C _ 25C
    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
    [partitions.csv]
2026-03-04 V026
    Changes V026: Added CheckWIFIcommand() to avoid WIFI crashes when a command take several seconds to end, like LEDtest()
    Changes V026: changed delimiters in time log. Temp 15C _ 25C -> 10C - 30C and color calculation LED10.
    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
    [RTCcheckV05.fzz, RTCcheckV06.fzz, partitions.csv]
2026-03-18 Gerberfiles in V05 and V06
